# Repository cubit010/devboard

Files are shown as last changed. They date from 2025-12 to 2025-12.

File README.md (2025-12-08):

# Devboard
a devboard i hacked together with minimal sleep

total jlcpcb cost $28.7 (including local taxes and shipping)

5pcs pcb and 2pcs pcba

# BOM is the Devboard.csv file

# Summary:
Raspberry rp2040 microcontroller 
gpio 0-25 broken out, gpio26-29/adc0-3 also broken out 

similar pinout as raspberry pi pico, but with the gpio 25 broken out, trading a ground pin for a gpio

power pins moved to the top right of the board in a group, both vbus and 3v3

# Screenshots
## checkout (excluding tax)


## checkout (with tax)


## PCB Final


## PCB Routing


## PCB schematic


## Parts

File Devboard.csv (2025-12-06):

Id | Designator | Footprint | Quantity | Comment | Supplier and ref
1 | R3,R4 | R_0402_1005Metric | 2 | 27
2 | U2 | SOT-23 | 1 | MCP1700x-300xxTT
3 | C14,C13 | C_0603_1608Metric | 2 | 10uF
4 | C10,C9,C17,C11,C8,C7,C6,C5,C4,C3,C2 | C_0402_1005Metric | 11 | 0.1uF
5 | R5,R6 | R_0402_1005Metric | 2 | 1K
6 | U3 | Winbond_USON-8-1EP_3x2mm_P0.5mm_EP0.2x1.6mm | 1 | W25Q128JVS
7 | U1 | QFN-56-1EP_7x7mm_P0.4mm_EP3.2x3.2mm | 1 | RP2040
8 | Y1 | Crystal_SMD_3225-4Pin_3.2x2.5mm | 1 | 12 MHz
9 | SW1 | SW_Push_SPST_NO_Alps_SKRK | 1 | SW_Push
10 | R7 | R_0402_1005Metric | 1 | 10K
11 | R2,R1 | R_0402_1005Metric | 2 | 5.1K
12 | J4 | PinHeader_1x03_P2.54mm_Vertical | 1 | Conn_01x03
13 | J3,J2 | PinHeader_1x20_P2.54mm_Vertical | 2 | Conn_01x20
14 | C16,C15 | C_0402_1005Metric | 2 | 33pF
15 | C12,C1 | C_0402_1005Metric | 2 | 1uF
16 | J1 | USB_C_Receptacle_HRO_TYPE-C-31-M-12 | 1 | USB_C_Receptacle_USB2.0_14P

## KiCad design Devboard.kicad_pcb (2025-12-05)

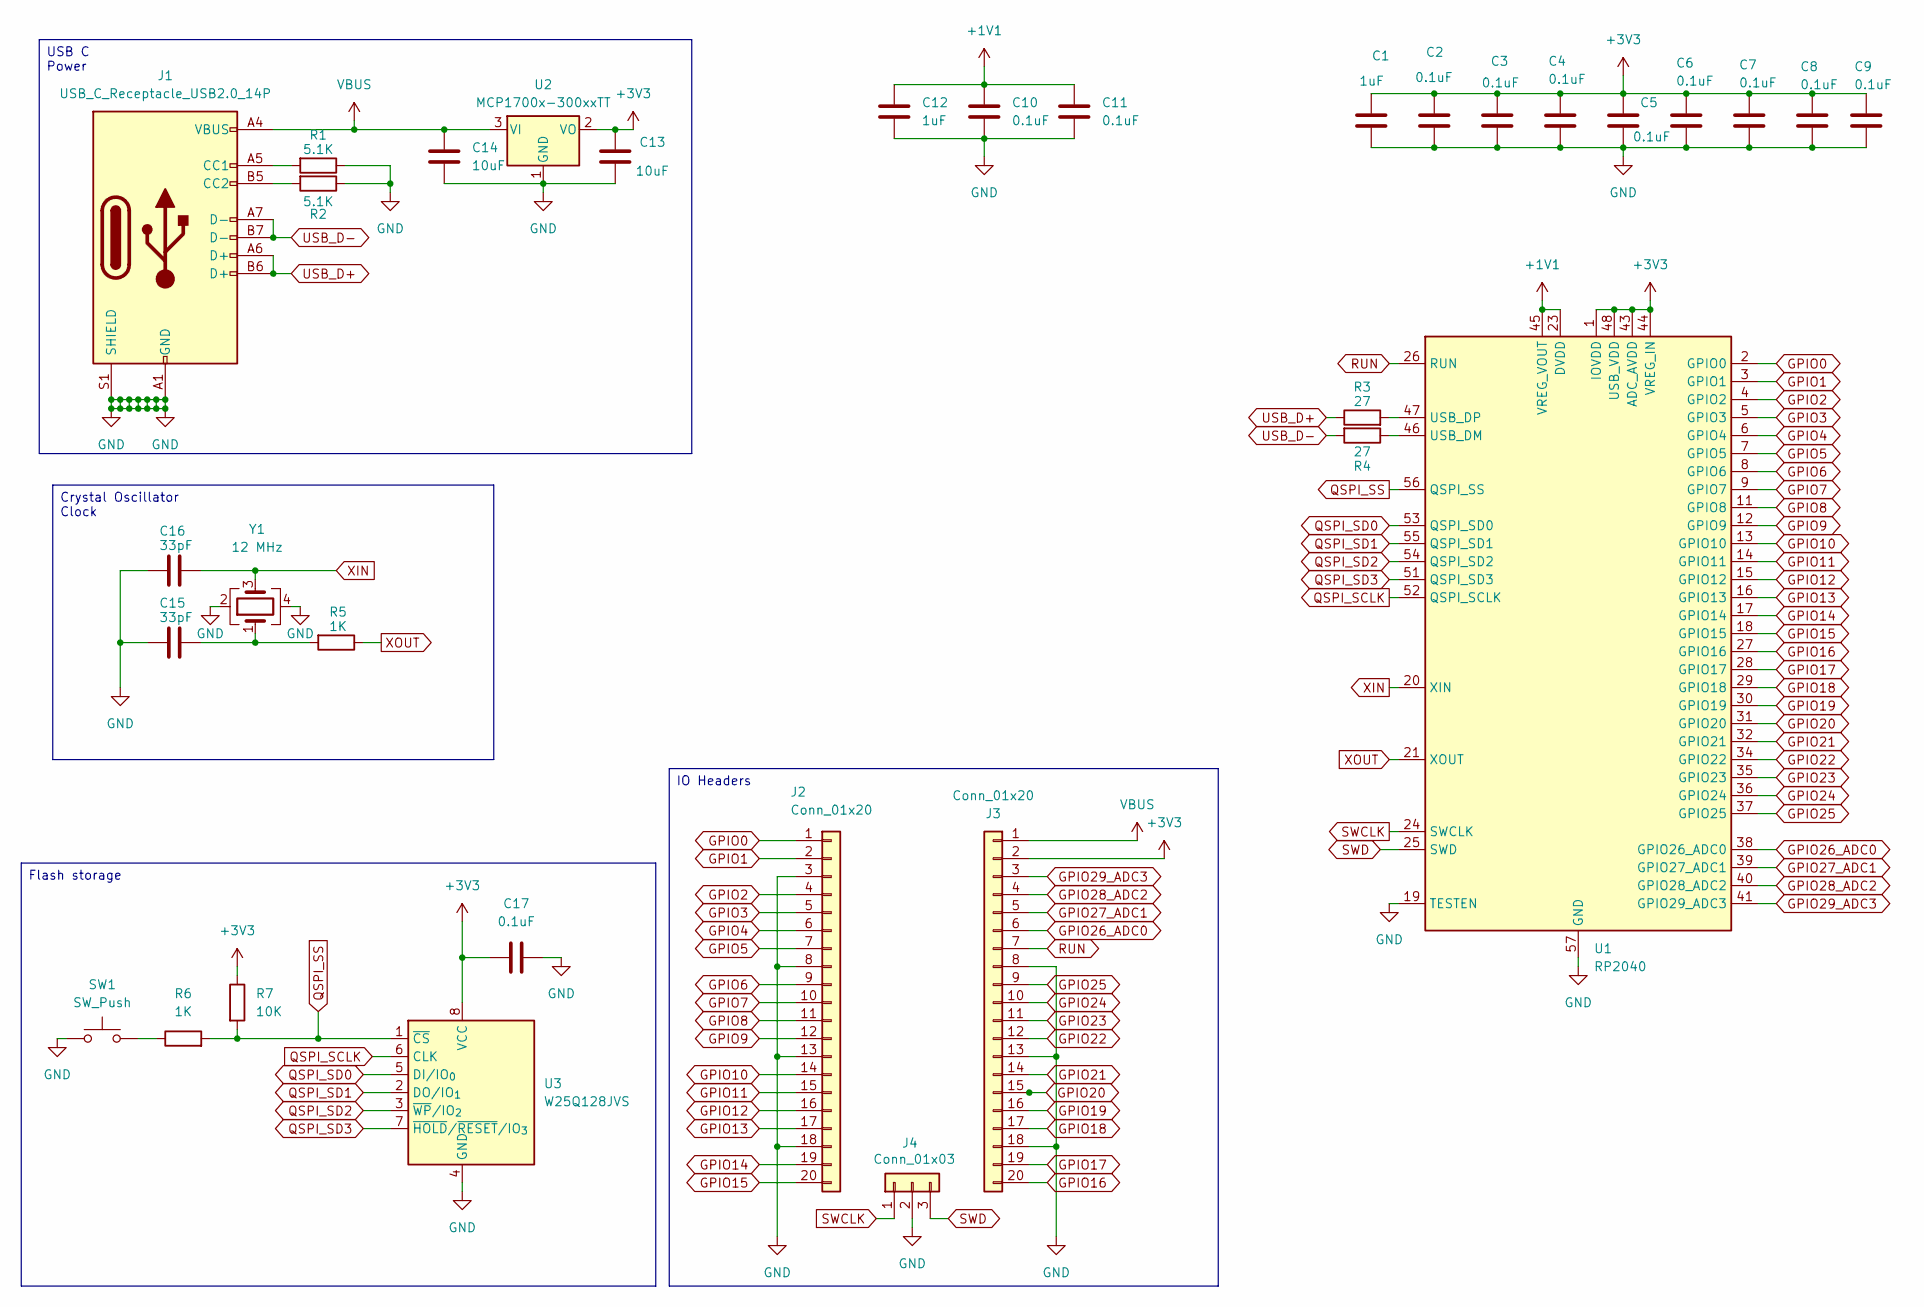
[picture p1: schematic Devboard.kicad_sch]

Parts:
C1, C12: 1uF; C_0402_1005Metric
C2, C3, C4, C5, C6, C7, C8, C9, C10, C11, C17: 0.1uF; C_0402_1005Metric
C13, C14: 10uF; C_0603_1608Metric
C15, C16: 33pF; C_0402_1005Metric
J1: USB_C_Receptacle_USB2.0_14P; USB_C_Receptacle_HRO_TYPE-C-31-M-12
J2, J3: Conn_01x20; PinHeader_1x20_P2.54mm_Vertical
J4: Conn_01x03; PinHeader_1x03_P2.54mm_Vertical
R1, R2: 5.1K; R_0402_1005Metric
R3, R4: 27; R_0402_1005Metric
R5, R6: 1K; R_0402_1005Metric
R7: 10K; R_0402_1005Metric
SW1: SW_Push; SW_Push_SPST_NO_Alps_SKRK
U1: RP2040; QFN-56-1EP_7x7mm_P0.4mm_EP3.2x3.2mm
U2: MCP1700x-300xxTT; SOT-23
U3: W25Q128JVS; Winbond_USON-8-1EP_3x2mm_P0.5mm_EP0.2x1.6mm
Y1: 12 MHz; Crystal_SMD_3225-4Pin_3.2x2.5mm

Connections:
+1V1: C10.1, C11.1, C12.1, U1.23 (DVDD), U1.45 (VREG_VOUT), U1.50 (DVDD)
+3V3: C1.1, C2.1, C3.1, C4.1, C5.1, C6.1, C7.1, C8.1, C9.1, C13.1, C17.1, J3.2, R7.1, U1.1 (IOVDD), U1.10 (IOVDD), U1.22 (IOVDD), U1.33 (IOVDD), U1.42 (IOVDD), U1.43 (ADC_AVDD), U1.44 (VREG_IN), U1.48 (USB_VDD), U1.49 (IOVDD), U2.2 (VO), U3.8 (VCC)
GND: C1.2, C2.2, C3.2, C4.2, C5.2, C6.2, C7.2, C8.2, C9.2, C10.2, C11.2, C12.2, C13.2, C14.2, C15.1, C16.1, C17.2, J1.A1 (GND), J1.A12 (GND), J1.B1 (GND), J1.B12 (GND), J1.S1 (SHIELD), J2.3, J2.8, J2.13, J2.18, J3.8, J3.13, J3.18, J4.2, R1.1, R2.1, SW1.1, U1.19 (TESTEN), U1.57 (GND), U2.1 (GND), U3.4 (GND), Y1.2, Y1.4
GPIO0: J2.1, U1.2 (GPIO0)
GPIO1: J2.2, U1.3 (GPIO1)
GPIO2: J2.4, U1.4 (GPIO2)
GPIO3: J2.5, U1.5 (GPIO3)
GPIO4: J2.6, U1.6 (GPIO4)
GPIO5: J2.7, U1.7 (GPIO5)
GPIO6: J2.9, U1.8 (GPIO6)
GPIO7: J2.10, U1.9 (GPIO7)
GPIO8: J2.11, U1.11 (GPIO8)
GPIO9: J2.12, U1.12 (GPIO9)
GPIO10: J2.14, U1.13 (GPIO10)
GPIO11: J2.15, U1.14 (GPIO11)
GPIO12: J2.16, U1.15 (GPIO12)
GPIO13: J2.17, U1.16 (GPIO13)
GPIO14: J2.19, U1.17 (GPIO14)
GPIO15: J2.20, U1.18 (GPIO15)
GPIO16: J3.20, U1.27 (GPIO16)
GPIO17: J3.19, U1.28 (GPIO17)
GPIO18: J3.17, U1.29 (GPIO18)
GPIO19: J3.16, U1.30 (GPIO19)
GPIO20: J3.15, U1.31 (GPIO20)
GPIO21: J3.14, U1.32 (GPIO21)
GPIO22: J3.12, U1.34 (GPIO22)
GPIO23: J3.11, U1.35 (GPIO23)
GPIO24: J3.10, U1.36 (GPIO24)
GPIO25: J3.9, U1.37 (GPIO25)
GPIO26_ADC0: J3.6, U1.38 (GPIO26_ADC0)
GPIO27_ADC1: J3.5, U1.39 (GPIO27_ADC1)
GPIO28_ADC2: J3.4, U1.40 (GPIO28_ADC2)
GPIO29_ADC3: J3.3, U1.41 (GPIO29_ADC3)
unnamed: C15.2, R5.2, Y1.1
unnamed: J1.A5 (CC1), R1.2
unnamed: J1.B5 (CC2), R2.2
unnamed: R6.1, SW1.2
unnamed: R4.1, U1.46 (USB_DM)
unnamed: R3.2, U1.47 (USB_DP)
QSPI_SCLK: U1.52 (QSPI_SCLK), U3.6 (CLK)
QSPI_SD0: U1.53 (QSPI_SD0), U3.5 (DI/IO_{0})
QSPI_SD1: U1.55 (QSPI_SD1), U3.2 (DO/IO_{1})
QSPI_SD2: U1.54 (QSPI_SD2), U3.3 (~WP/IO_{2})
QSPI_SD3: U1.51 (QSPI_SD3), U3.7 (~HOLD/~RESET/IO_{3})
QSPI_SS: R6.2, R7.2, U1.56 (QSPI_SS), U3.1 (~CS)
RUN: J3.7, U1.26 (RUN)
SWCLK: J4.1, U1.24 (SWCLK)
SWD: J4.3, U1.25 (SWD)
USB_D+: J1.A6 (D+), J1.B6 (D+), R3.1
USB_D-: J1.A7 (D-), J1.B7 (D-), R4.2
VBUS: C14.1, J1.A4 (VBUS), J1.A9 (VBUS), J1.B4 (VBUS), J1.B9 (VBUS), J3.1, U2.3 (VI)
XIN: C16.2, U1.20 (XIN), Y1.3
XOUT: R5.1, U1.21 (XOUT)

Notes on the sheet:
USB C Power
Crystal Oscillator Clock
IO Headers
Flash storage

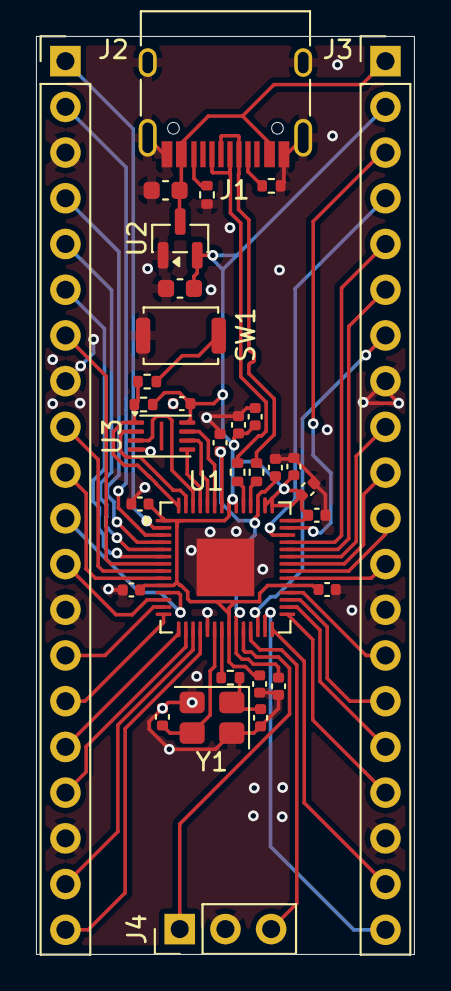
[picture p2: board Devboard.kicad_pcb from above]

Board: 2 copper layers, 21.0 x 51.0 mm, 33 parts (0 on the bottom side), 53 nets.

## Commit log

2025-12-05 pcb files
    [Devboard.kicad_pcb, Devboard.kicad_sch]
2025-12-06 upload bom
    boom boom bom pow
    [Devboard.csv]
2025-12-06 Update README
    Clarified the power pin arrangement in the summary.
2025-12-06 Add PCB images to README
    Added images for PCB final, routing, and schematic.
2025-12-06 add production files
    [Devboard-B_Cu.gbr, Devboard-B_Mask.gbr, Devboard-B_Paste.gbr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]
